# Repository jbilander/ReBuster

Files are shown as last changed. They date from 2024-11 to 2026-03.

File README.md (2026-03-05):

# ReBuster
A drop-in replacement PCB for the Amiga Super Buster chip

This is WORK IN PROGRESS. If you generate gerbers and order PCBs from this source you are doing so completely at your own risk!.

***

<a href="images/ReBuster_pic1.jpg">
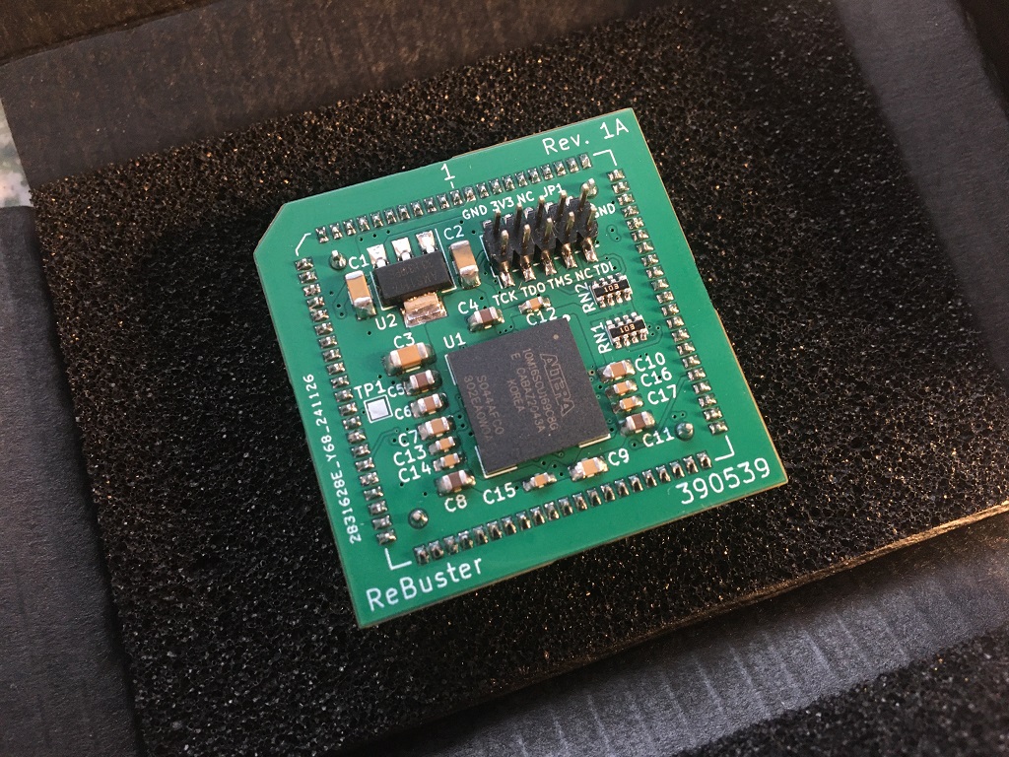
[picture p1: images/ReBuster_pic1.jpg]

</a>
<a href="images/ReBuster_pic2.jpg">
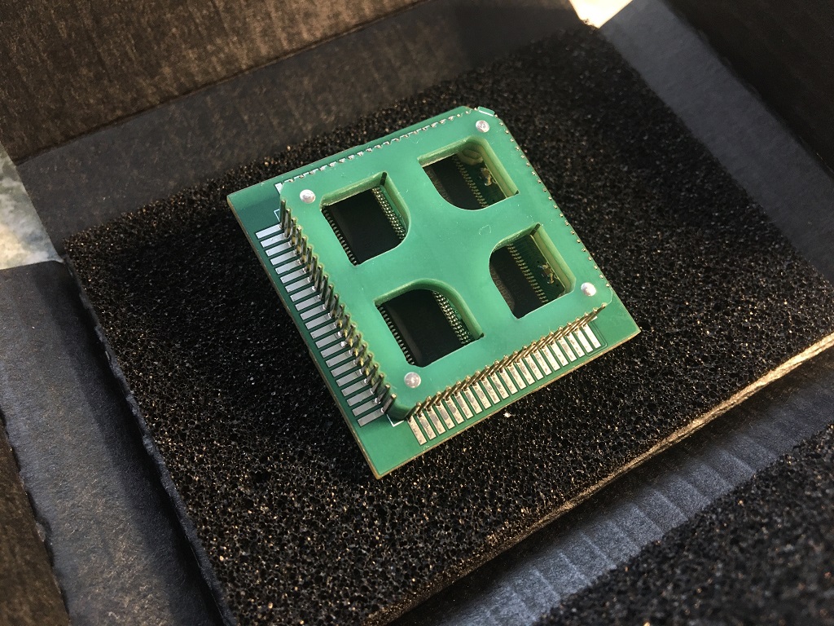
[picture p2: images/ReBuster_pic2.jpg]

</a>
<a href="images/ReBuster_pic3.jpg">
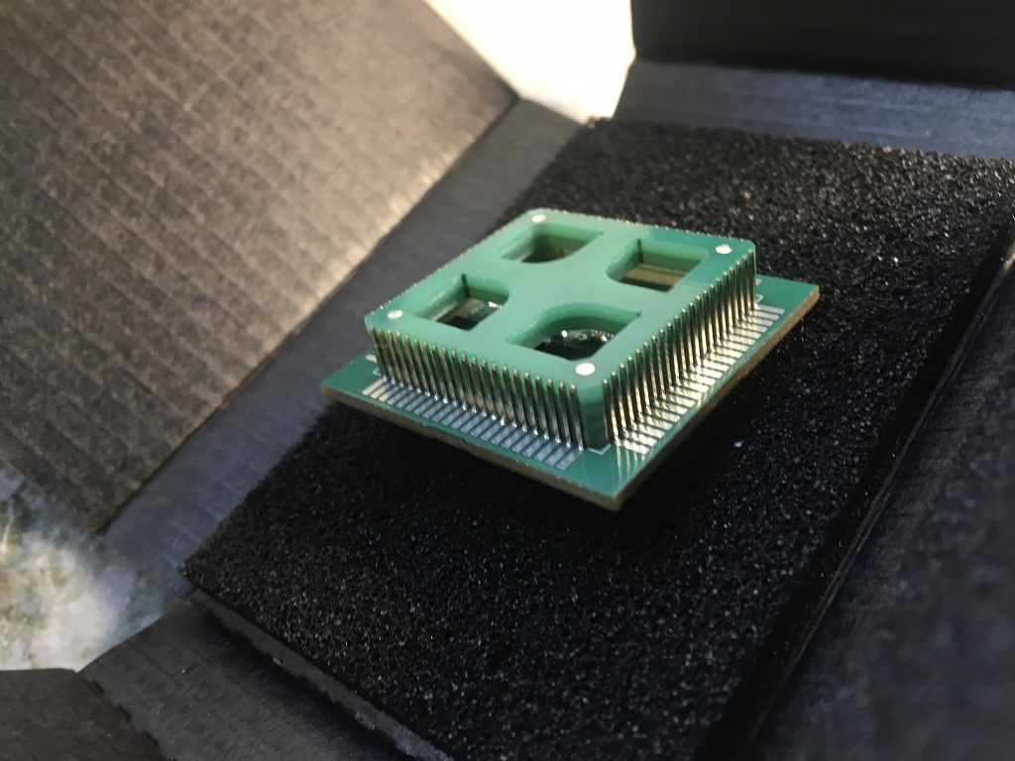
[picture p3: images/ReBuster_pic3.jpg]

</a>

***

<a href="images/ReBuster_screenshot_pic1.png">
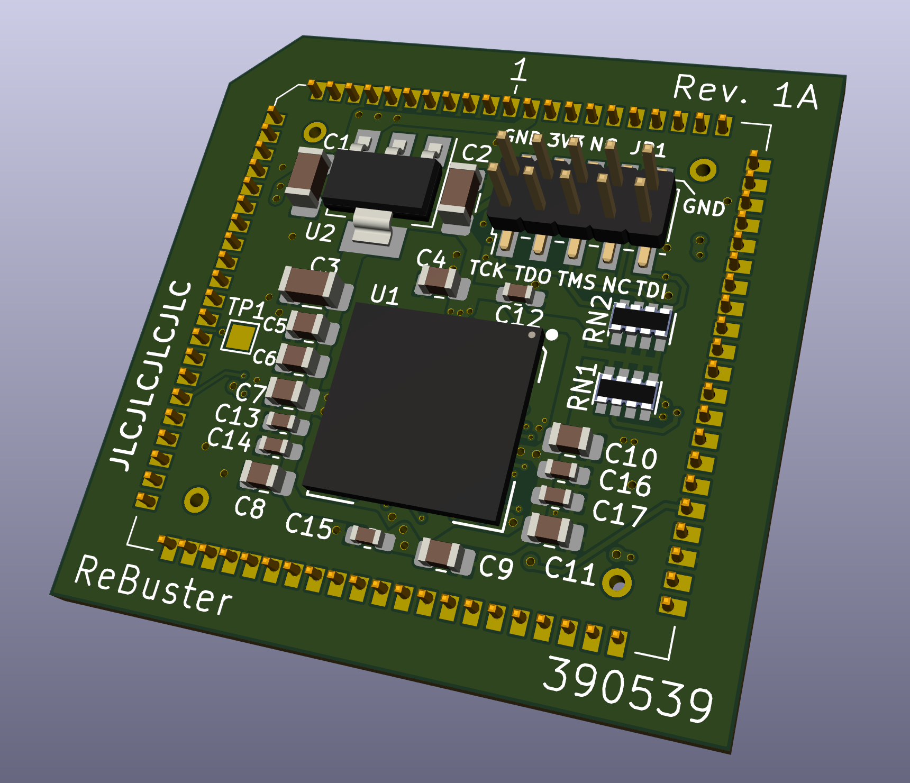
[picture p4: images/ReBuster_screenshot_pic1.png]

</a>
<br />
<a href="images/ReBuster_screenshot_pic2.png">
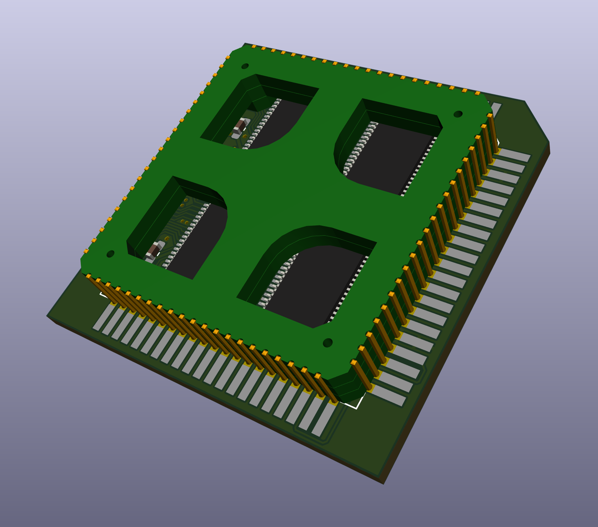
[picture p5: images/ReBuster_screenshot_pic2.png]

</a>
<br />
<a href="images/ReBuster_screenshot_pic3.png">
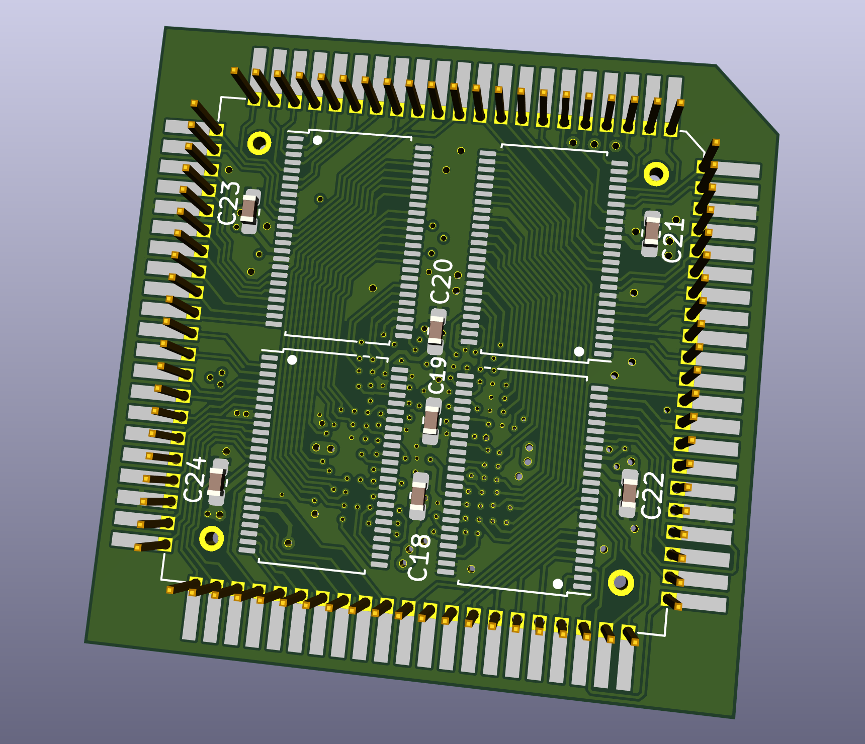
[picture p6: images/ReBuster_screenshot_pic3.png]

</a>

***

<a href="images/pin_assignment_rebuster_rev2a.jpg">
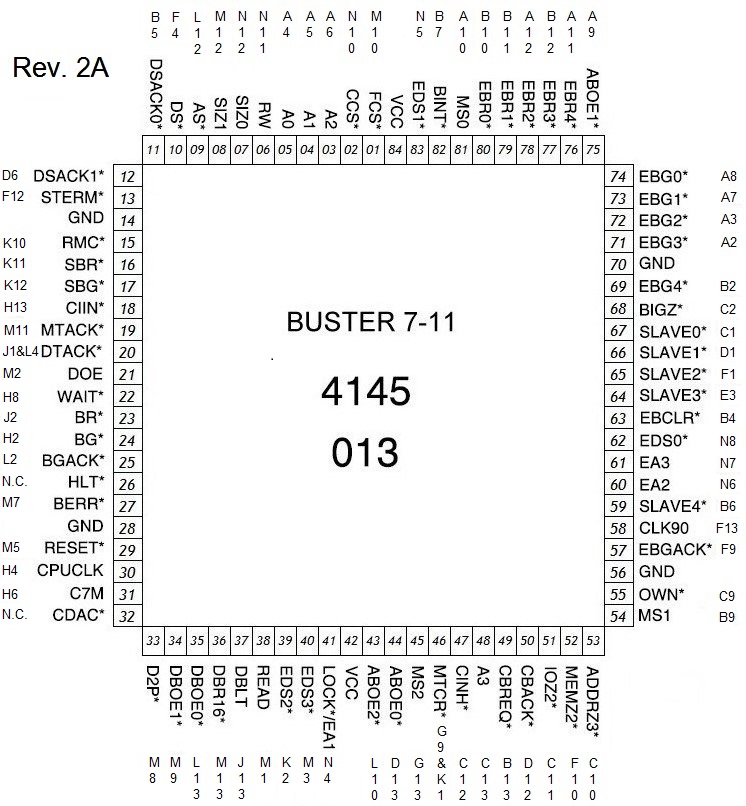
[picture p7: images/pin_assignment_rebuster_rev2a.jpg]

</a>

***

BOM Rev. 2A
---------
Reference  | Name/Value   | Package | Notes
-|-|-|-|
U1 | 10M04SCU169C8G  | BGA-169 11.0x11.0mm_Layout13x13 | Max 10 FPGA [10M04SCU169C8G](https://www.mouser.com/ProductDetail/989-10M04SCU169C8G)
U2 | LM1117-3.3 | SOT-223 | Low-Dropout Linear Regulator 3.3 Volt
U3,U5,U6 | SN74CBTD16210 | TSSOP-48 6.1x12.5mm_P0.5mm | 20-BIT FET Bus switch with level shifting, high-speed TTL-compatible. [74CBTD16210DGGR](https://www.mouser.com/ProductDetail/595-74CBTD16210DGGR)
U4 | SN74LVC16245ADGVR | TSSOP-48_4.4x9.7mm_P0.4mm | 16-bit (dual-octal) noninverting bus transceiver [SN74LVC16245ADGVR](https://www.mouser.com/ProductDetail/595-SNLVC16245ADGVR)
U7 | 74LVC2G07GV | TSOP-6_1.65x3.05mm_P0.95mm | Open Drain noninverting line driver [74LVC2G07GV](https://www.mouser.com/ProductDetail/771-LVC2G07GV125)
U8 | Winslow PLCC-84 Plug | PLCC-84 Plug | Optionally use a home made plug (stacked PCBs)
U9 | PLCC-84_TH_pin_holes | TH_plug_pins | Pins that could be used with the DIY-plug PCBs rev1d for manual fitting, L8.7mm [Aliexpress](https://www.aliexpress.com/item/32893608810.html).
RN1, RN2 | CAY16-1002F4LF RES ARRAY 4 Resistors 10k Ω | 1206 | [CAY16-1002F4LF](https://www.mouser.com/ProductDetail/652-CAY16-1002F4LF)
C1-3 | Capacitor 10uF | 1206 | 
C4,C5,C8,C11 | Capacitor 1uF | 0805 | 
C6,C7,C9,C10 | Capacitor 0.1uF = 100nF | 0805 | 
C12-C19, C21-C23 | Capacitor 0.01uF = 10nF | 0603 |
C20, C24-C28 | Capacitor 0.1uF = 100nF | 0603 |
JTAG | SMT Pin Header Male | SMT 2 x 5 Pin 2.0mm pitch |

***

***

<a href="images/pin_assignment_rebuster_rev1a.jpg">
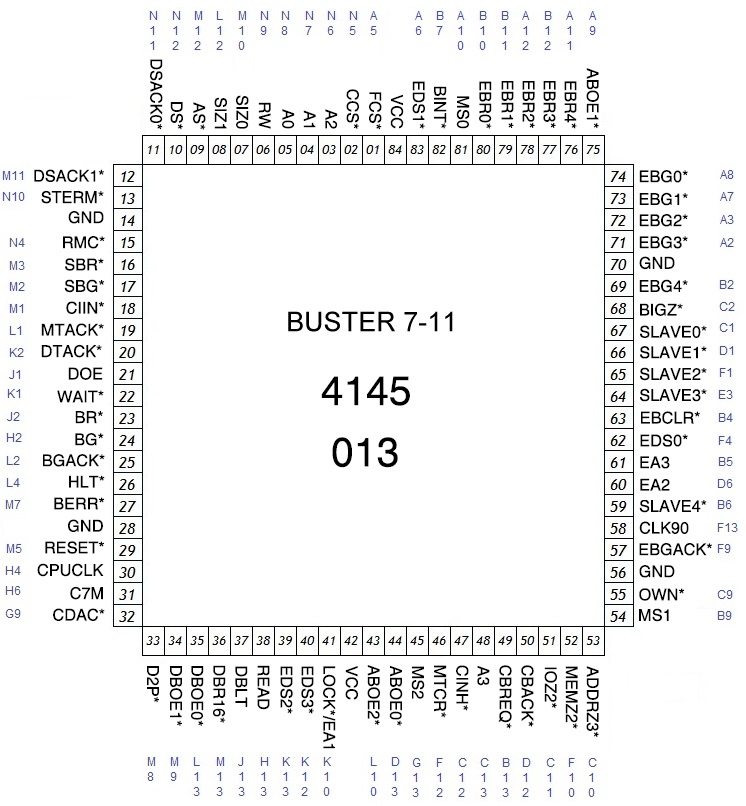
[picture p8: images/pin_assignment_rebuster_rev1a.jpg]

</a>

***

BOM Rev. 1A
---------
Reference  | Name/Value   | Package | Notes
-|-|-|-|
U1 | GW1N-UV9UG169C6/I5  | BGA-169 11.0x11.0mm_Layout13x13 | Gowin FPGA [GW1N-UV9UG169](https://www.mouser.com/ProductDetail/192-GW1NUV9UG169C6I5)
U2 | LM1117-3.3 | SOT-223 | Low-Dropout Linear Regulator 3.3 Volt
U3-U6 | SN74CBTD16210 | TSSOP-48 6.1x12.5mm_P0.5mm | 20-BIT FET Bus switch with level shifting, high-speed TTL-compatible. [74CBTD16210DGGR](https://www.mouser.com/ProductDetail/595-74CBTD16210DGGR)
U7 | Winslow PLCC-84 Plug | PLCC-84 Plug | Optionally use a home made plug (stacked PCBs)
U8 | PLCC-84_TH_pin_holes | TH_plug_pins | Pins that could be used with the DIY-plug PCBs rev1d for manual fitting, L8.7mm [Aliexpress](https://www.aliexpress.com/item/32893608810.html).
RN1, RN2 | CAY16A-4701F4LF RES ARRAY 4 Resistors 4.7k Ω | 1206 | [CAY16A-4701F4LF](https://wwww.mouser.com/ProductDetail/652-CAY16A-4701F4LF)
C1-3 | Capacitor 10uF | 1206 | 
C4,C5,C8,C11 | Capacitor 1uF | 0805 | 
C6,C7,C9,C10 | Capacitor 0.1uF = 100nF | 0805 | 
C12-C19 | Capacitor 0.01uF = 10nF | 0603 |
C20 | Capacitor 0.1uF = 100nF | 0603 |
C21-C24 | Capacitor 0.01uF = 10nF | 0603 |
JTAG | SMT Pin Header Male | SMT 2 x 5 Pin 2.0mm pitch |

***

When ordering from JLCPCB select:

Specify Layer Sequence: Yes

    L1(Top layer):    F_Cu.gbr
    L2(Inner layer1): GND_Cu.gbr
    L3(Inner layer2): VCC_Cu.gbr
    L4(Bottom layer): B_Cu.gbr

Remove Order Number: 

    Specify a location

This will notify JLC where to put the order number, they will replace the "JLCJLCJLCJLC" silkscreen label.

***

[][cc-by-sa]

This work is licensed under a
[Creative Commons Attribution-ShareAlike 4.0 International License][cc-by-sa].

[][cc-by-sa]

[cc-by-sa]: http://creativecommons.org/licenses/by-sa/4.0/
[cc-by-sa-image]: https://licensebuttons.net/l/by-sa/4.0/88x31.png
[cc-by-sa-shield]: https://img.shields.io/badge/License-CC%20BY--SA%204.0-lightgrey.svg

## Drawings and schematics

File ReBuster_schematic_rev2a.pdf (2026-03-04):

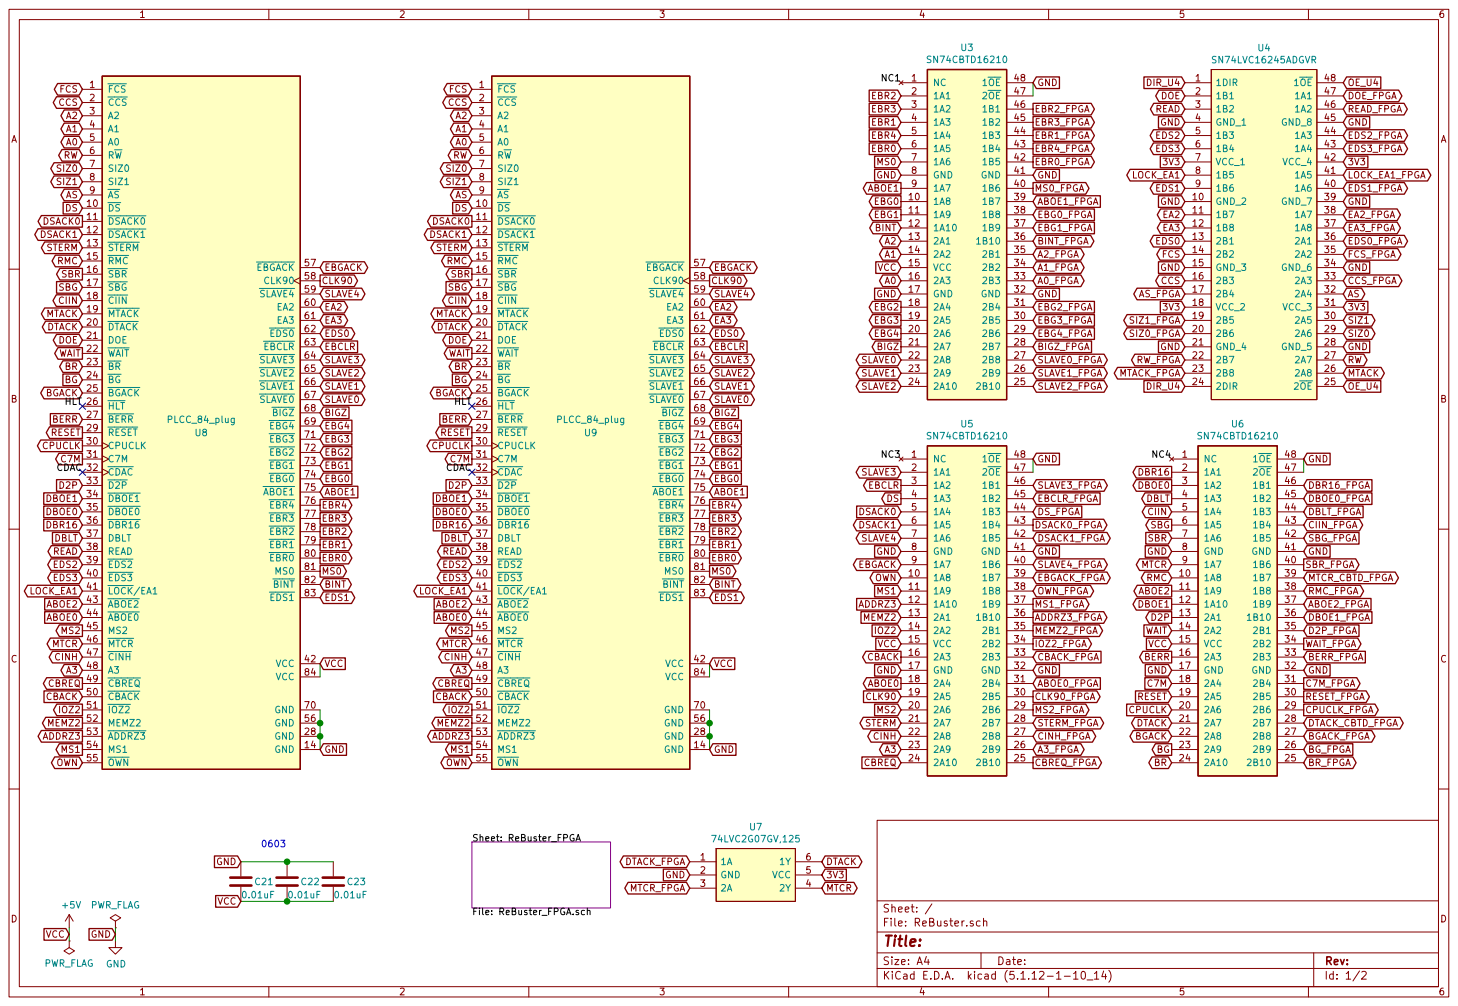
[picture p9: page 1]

SBG
SLAVE4 EA2 EA3 DTACK
CIIN MTACK WAIT BR
ABOE2 CPUCLK DOE
BGACK READ
ABOE0 BERR MTCR
DBLT RESET C7M

Id: 1/2 Title: File: ReBuster.sch Sheet: / Sheet: ReBuster_FPGA

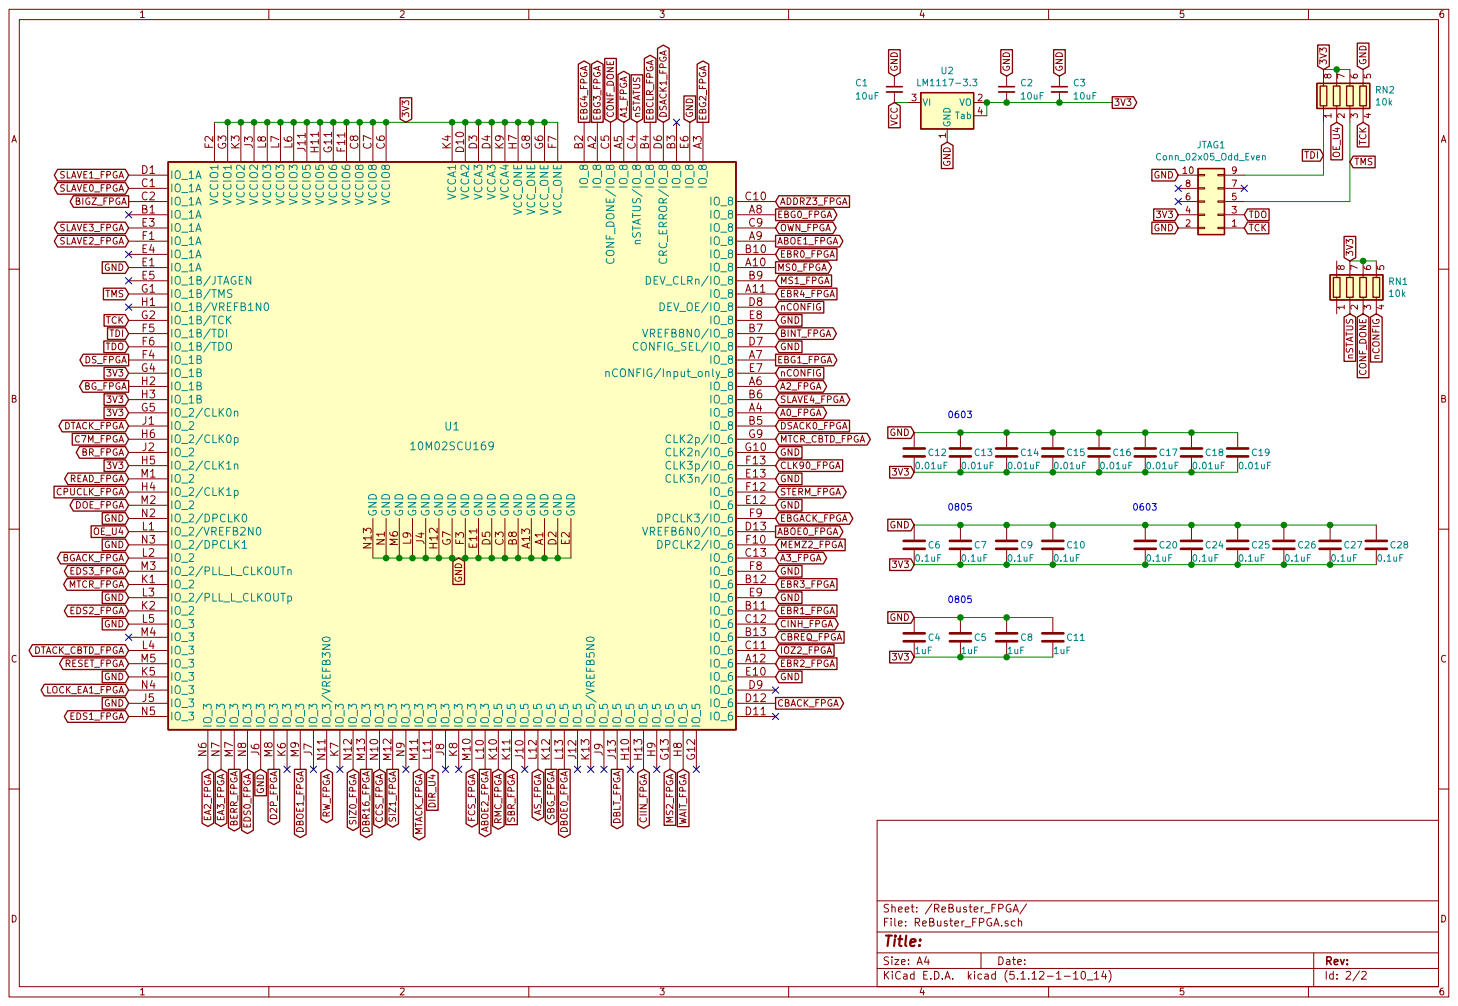
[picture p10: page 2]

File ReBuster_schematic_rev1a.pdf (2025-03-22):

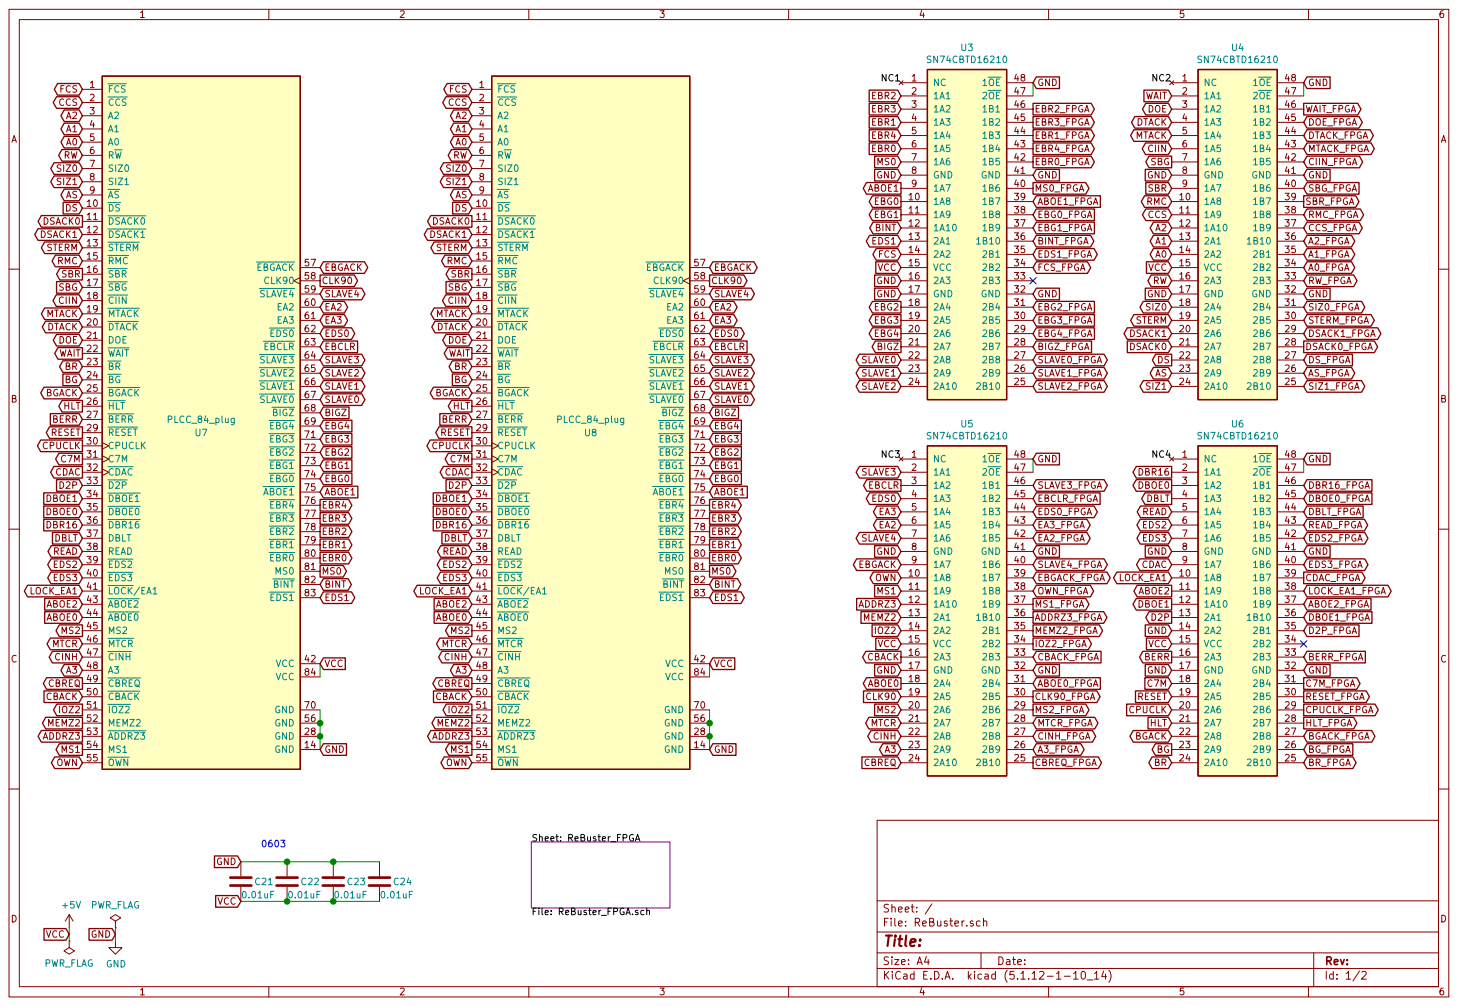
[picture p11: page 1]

SBG
CIIN MTACK WAIT BR

Id: 1/2 Title: File: ReBuster.sch Sheet: / Sheet: ReBuster_FPGA

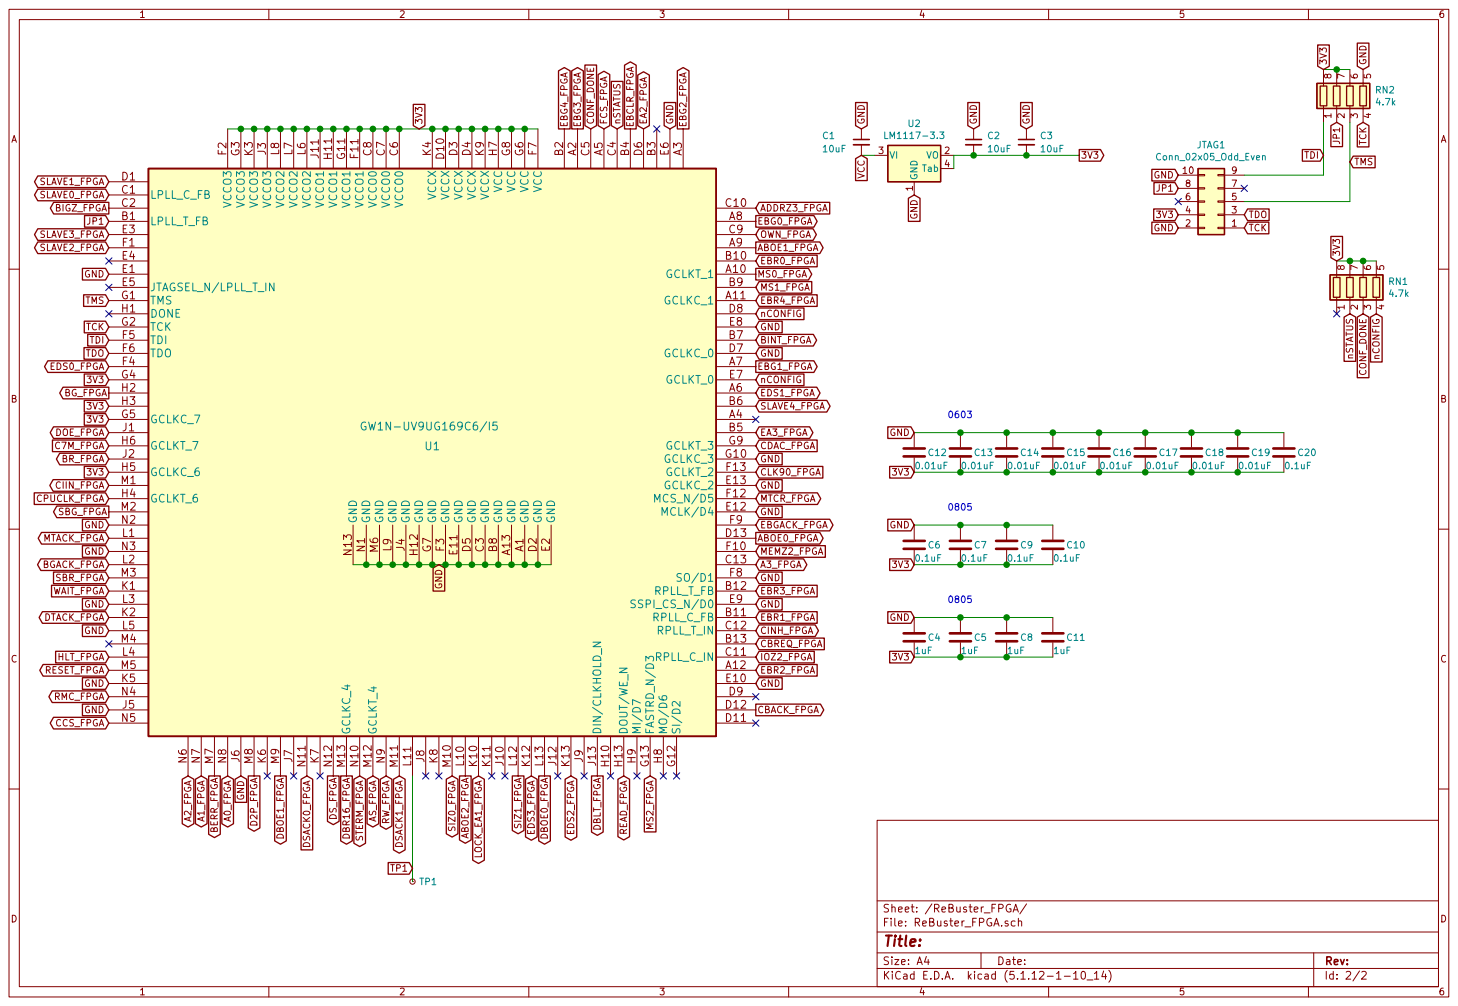
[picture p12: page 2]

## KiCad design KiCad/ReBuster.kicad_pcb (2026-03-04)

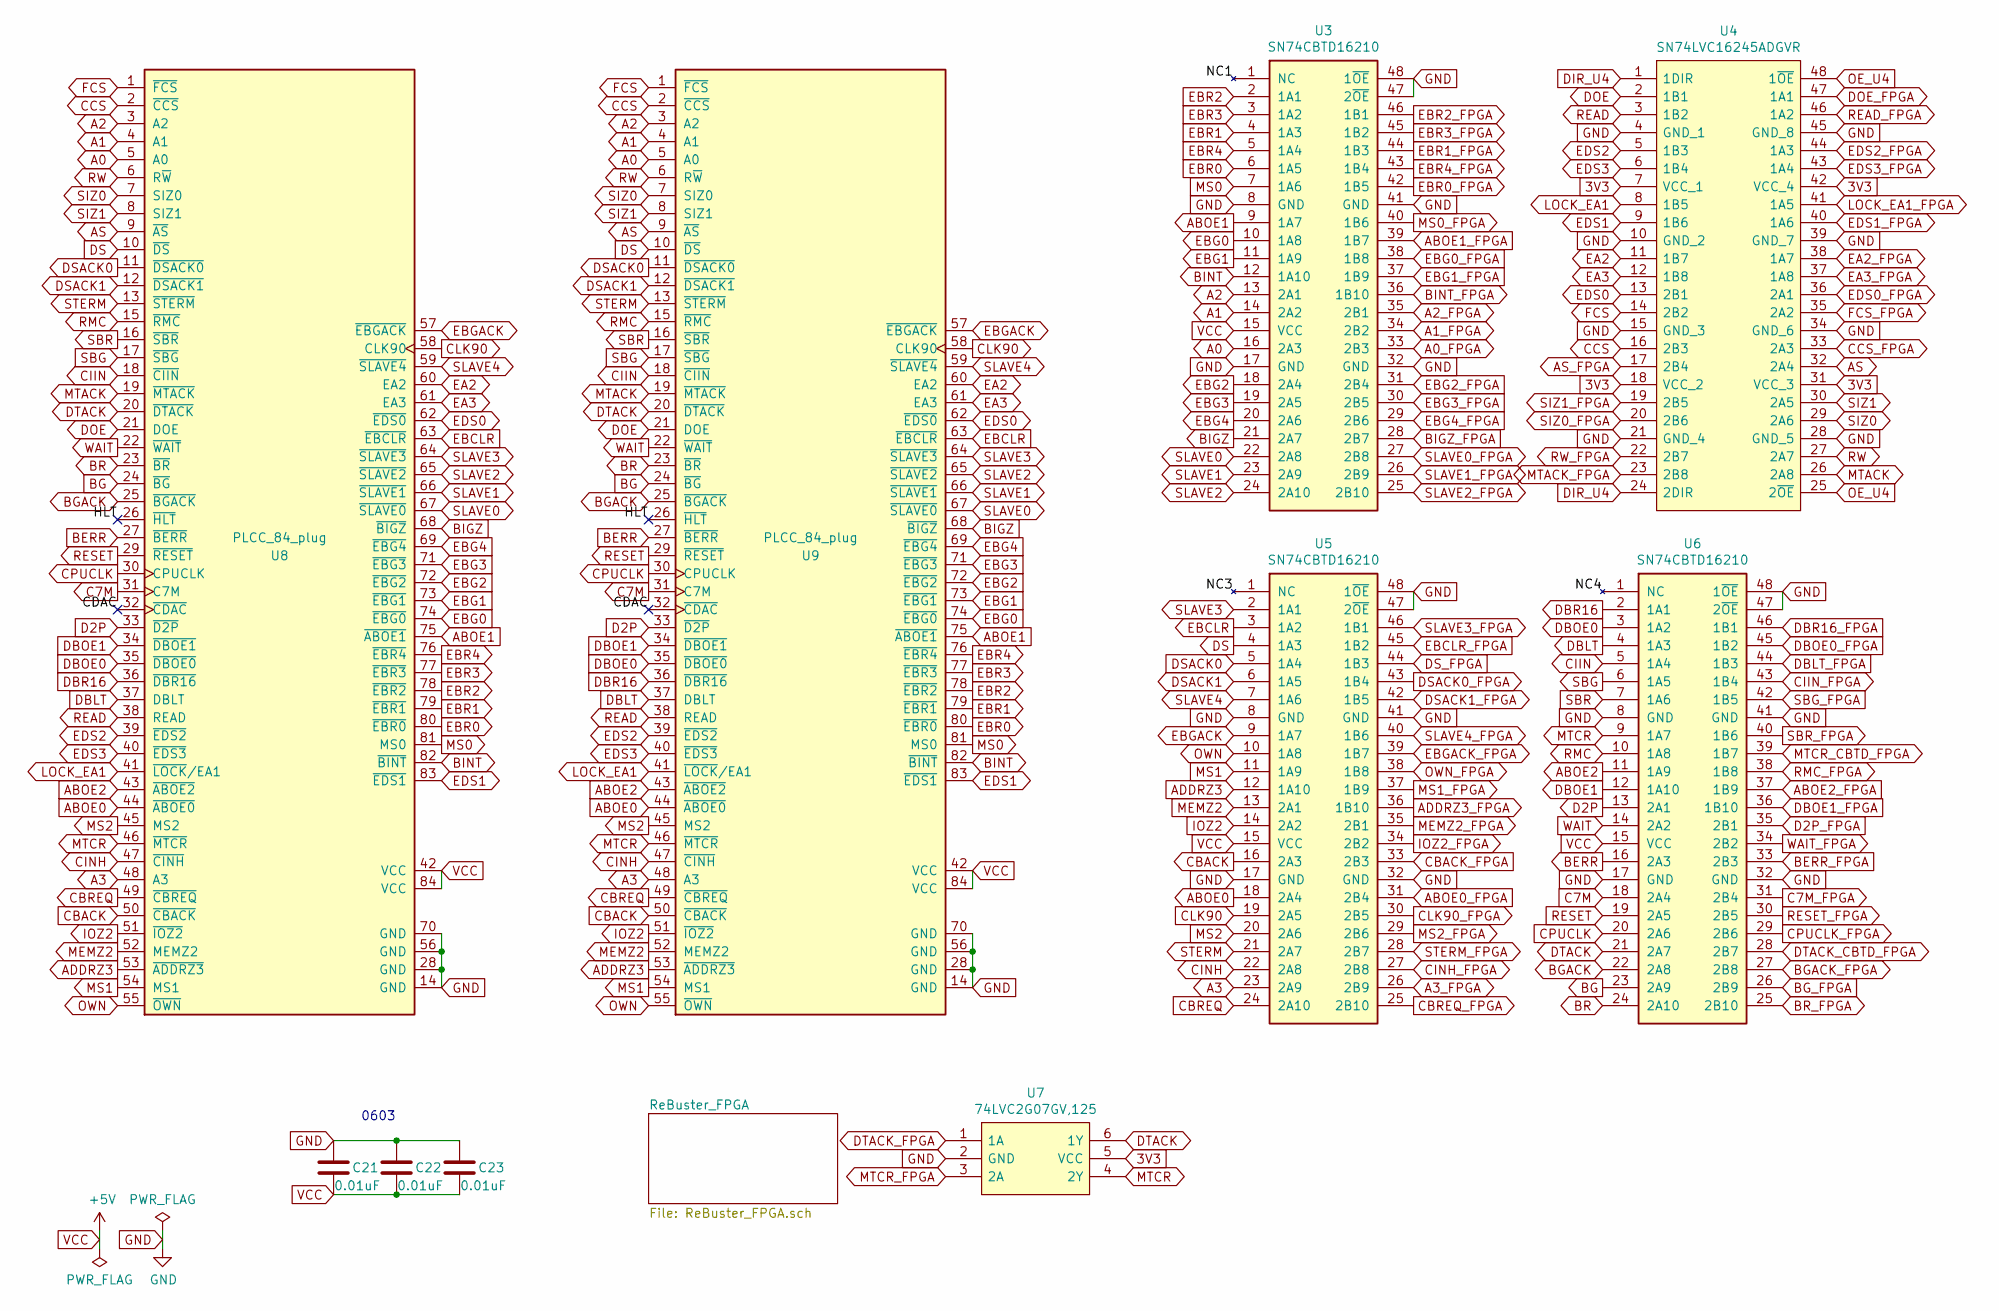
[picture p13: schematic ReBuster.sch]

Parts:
C21, C22, C23: 0.01uF; C_0603_1608Metric_Pad1.05x0.95mm_HandSolder
U3, U5, U6: SN74CBTD16210; TSSOP-48_6.1x12.5mm_P0.5mm_padLength_1mm
U4: SN74LVC16245ADGVR; TSSOP-48_4.4x9.7mm_P0.4mm_custom
U7: 74LVC2G07GV,125; TSOP-6_1.65x3.05mm_P0.95mm
U8: PLCC_84_plug; PLCC-84_Plug_P1.27mm_mirrored
U9: PLCC_84_plug; PLCC-84_TH_pin_holes

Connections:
3V3: U4.7 (VCC_1), U4.18 (VCC_2), U4.31 (VCC_3), U4.42 (VCC_4), U7.5 (VCC); also elsewhere on the board
/CDAC: U8.32 (~CDAC), U9.32 (~CDAC)
/HLT: U8.26 (~HLT), U9.26 (~HLT)
/NC1: U3.1 (NC)
/NC3: U5.1 (NC)
/NC4: U6.1 (NC)
A0: U3.16 (2A3), U8.5 (A0), U9.5 (A0)
A0_FPGA: U3.33 (2B3); also elsewhere on the board
A1: U3.14 (2A2), U8.4 (A1), U9.4 (A1)
A1_FPGA: U3.34 (2B2); also elsewhere on the board
A2: U3.13 (2A1), U8.3 (A2), U9.3 (A2)
A2_FPGA: U3.35 (2B1); also elsewhere on the board
A3: U5.23 (2A9), U8.48 (A3), U9.48 (A3)
A3_FPGA: U5.26 (2B9); also elsewhere on the board
ABOE0: U5.18 (2A4), U8.44 (~ABOE0), U9.44 (~ABOE0)
ABOE0_FPGA: U5.31 (2B4); also elsewhere on the board
ABOE1: U3.9 (1A7), U8.75 (~ABOE1), U9.75 (~ABOE1)
ABOE1_FPGA: U3.39 (1B7); also elsewhere on the board
ABOE2: U6.11 (1A9), U8.43 (~ABOE2), U9.43 (~ABOE2)
ABOE2_FPGA: U6.37 (1B9); also elsewhere on the board
ADDRZ3: U5.12 (1A10), U8.53 (~ADDRZ3), U9.53 (~ADDRZ3)
ADDRZ3_FPGA: U5.36 (1B10); also elsewhere on the board
AS: U4.32 (2A4), U8.9 (~AS), U9.9 (~AS)
AS_FPGA: U4.17 (2B4); also elsewhere on the board
BERR: U6.16 (2A3), U8.27 (~BERR), U9.27 (~BERR)
BERR_FPGA: U6.33 (2B3); also elsewhere on the board
BG: U6.23 (2A9), U8.24 (~BG), U9.24 (~BG)
BGACK: U6.22 (2A8), U8.25 (~BGACK), U9.25 (~BGACK)
BGACK_FPGA: U6.27 (2B8); also elsewhere on the board
BG_FPGA: U6.26 (2B9); also elsewhere on the board
BIGZ: U3.21 (2A7), U8.68 (~BIGZ), U9.68 (~BIGZ)
BIGZ_FPGA: U3.28 (2B7); also elsewhere on the board
BINT: U3.12 (1A10), U8.82 (~BINT), U9.82 (~BINT)
BINT_FPGA: U3.36 (1B10); also elsewhere on the board
BR: U6.24 (2A10), U8.23 (~BR), U9.23 (~BR)
BR_FPGA: U6.25 (2B10); also elsewhere on the board
C7M: U6.18 (2A4), U8.31 (C7M), U9.31 (C7M)
C7M_FPGA: U6.31 (2B4); also elsewhere on the board
CBACK: U5.16 (2A3), U8.50 (~CBACK), U9.50 (~CBACK)
CBACK_FPGA: U5.33 (2B3); also elsewhere on the board
CBREQ: U5.24 (2A10), U8.49 (~CBREQ), U9.49 (~CBREQ)
CBREQ_FPGA: U5.25 (2B10); also elsewhere on the board
CCS: U4.16 (2B3), U8.2 (~CCS), U9.2 (~CCS)
CCS_FPGA: U4.33 (2A3); also elsewhere on the board
CIIN: U6.5 (1A4), U8.18 (~CIIN), U9.18 (~CIIN)
CIIN_FPGA: U6.43 (1B4); also elsewhere on the board
CINH: U5.22 (2A8), U8.47 (~CINH), U9.47 (~CINH)
CINH_FPGA: U5.27 (2B8); also elsewhere on the board
CLK90: U5.19 (2A5), U8.58 (CLK90), U9.58 (CLK90)
CLK90_FPGA: U5.30 (2B5); also elsewhere on the board
CPUCLK: U6.20 (2A6), U8.30 (CPUCLK), U9.30 (CPUCLK)
CPUCLK_FPGA: U6.29 (2B6); also elsewhere on the board
D2P: U6.13 (2A1), U8.33 (~D2P), U9.33 (~D2P)
D2P_FPGA: U6.35 (2B1); also elsewhere on the board
DBLT: U6.4 (1A3), U8.37 (DBLT), U9.37 (DBLT)
DBLT_FPGA: U6.44 (1B3); also elsewhere on the board
DBOE0: U6.3 (1A2), U8.35 (~DBOE0), U9.35 (~DBOE0)
DBOE0_FPGA: U6.45 (1B2); also elsewhere on the board
DBOE1: U6.12 (1A10), U8.34 (~DBOE1), U9.34 (~DBOE1)
DBOE1_FPGA: U6.36 (1B10); also elsewhere on the board
DBR16: U6.2 (1A1), U8.36 (~DBR16), U9.36 (~DBR16)
DBR16_FPGA: U6.46 (1B1); also elsewhere on the board
DIR_U4: U4.1 (1DIR), U4.24 (2DIR); also elsewhere on the board
DOE: U4.2 (1B1), U8.21 (DOE), U9.21 (DOE)
DOE_FPGA: U4.47 (1A1); also elsewhere on the board
DS: U5.4 (1A3), U8.10 (~DS), U9.10 (~DS)
DSACK0: U5.5 (1A4), U8.11 (~DSACK0), U9.11 (~DSACK0)
DSACK0_FPGA: U5.43 (1B4); also elsewhere on the board
DSACK1: U5.6 (1A5), U8.12 (~DSACK1), U9.12 (~DSACK1)
DSACK1_FPGA: U5.42 (1B5); also elsewhere on the board
DS_FPGA: U5.44 (1B3); also elsewhere on the board
DTACK: U6.21 (2A7), U7.6 (1Y), U8.20 (~DTACK), U9.20 (~DTACK)
DTACK_CBTD_FPGA: U6.28 (2B7); also elsewhere on the board
DTACK_FPGA: U7.1 (1A); also elsewhere on the board
EA2: U4.11 (1B7), U8.60 (EA2), U9.60 (EA2)
EA2_FPGA: U4.38 (1A7); also elsewhere on the board
EA3: U4.12 (1B8), U8.61 (EA3), U9.61 (EA3)
EA3_FPGA: U4.37 (1A8); also elsewhere on the board
EBCLR: U5.3 (1A2), U8.63 (~EBCLR), U9.63 (~EBCLR)
EBCLR_FPGA: U5.45 (1B2); also elsewhere on the board
EBG0: U3.10 (1A8), U8.74 (~EBG0), U9.74 (~EBG0)
EBG0_FPGA: U3.38 (1B8); also elsewhere on the board
EBG1: U3.11 (1A9), U8.73 (~EBG1), U9.73 (~EBG1)
EBG1_FPGA: U3.37 (1B9); also elsewhere on the board
EBG2: U3.18 (2A4), U8.72 (~EBG2), U9.72 (~EBG2)
EBG2_FPGA: U3.31 (2B4); also elsewhere on the board
EBG3: U3.19 (2A5), U8.71 (~EBG3), U9.71 (~EBG3)
EBG3_FPGA: U3.30 (2B5); also elsewhere on the board
EBG4: U3.20 (2A6), U8.69 (~EBG4), U9.69 (~EBG4)
EBG4_FPGA: U3.29 (2B6); also elsewhere on the board
EBGACK: U5.9 (1A7), U8.57 (~EBGACK), U9.57 (~EBGACK)
EBGACK_FPGA: U5.39 (1B7); also elsewhere on the board
EBR0: U3.6 (1A5), U8.80 (~EBR0), U9.80 (~EBR0)
EBR0_FPGA: U3.42 (1B5); also elsewhere on the board
EBR1: U3.4 (1A3), U8.79 (~EBR1), U9.79 (~EBR1)
EBR1_FPGA: U3.44 (1B3); also elsewhere on the board
EBR2: U3.2 (1A1), U8.78 (~EBR2), U9.78 (~EBR2)
EBR2_FPGA: U3.46 (1B1); also elsewhere on the board
EBR3: U3.3 (1A2), U8.77 (~EBR3), U9.77 (~EBR3)
EBR3_FPGA: U3.45 (1B2); also elsewhere on the board
EBR4: U3.5 (1A4), U8.76 (~EBR4), U9.76 (~EBR4)
EBR4_FPGA: U3.43 (1B4); also elsewhere on the board
EDS0: U4.13 (2B1), U8.62 (~EDS0), U9.62 (~EDS0)
EDS0_FPGA: U4.36 (2A1); also elsewhere on the board
EDS1: U4.9 (1B6), U8.83 (~EDS1), U9.83 (~EDS1)
EDS1_FPGA: U4.40 (1A6); also elsewhere on the board
EDS2: U4.5 (1B3), U8.39 (~EDS2), U9.39 (~EDS2)
EDS2_FPGA: U4.44 (1A3); also elsewhere on the board
EDS3: U4.6 (1B4), U8.40 (~EDS3), U9.40 (~EDS3)
EDS3_FPGA: U4.43 (1A4); also elsewhere on the board
FCS: U4.14 (2B2), U8.1 (~FCS), U9.1 (~FCS)
FCS_FPGA: U4.35 (2A2); also elsewhere on the board
GND: C21.1, C22.1, C23.1, U3.8 (GND), U3.17 (GND), U3.32 (GND), U3.41 (GND), U3.47 (2~OE), U3.48 (1~OE), U4.4 (GND_1), U4.10 (GND_2), U4.15 (GND_3), U4.21 (GND_4), U4.28 (GND_5), U4.34 (GND_6), U4.39 (GND_7), U4.45 (GND_8), U5.8 (GND), U5.17 (GND), U5.32 (GND), U5.41 (GND), U5.47 (2~OE), U5.48 (1~OE), U6.8 (GND), U6.17 (GND), U6.32 (GND), U6.41 (GND), U6.47 (2~OE), U6.48 (1~OE), U7.2 (GND), U8.14 (GND), U8.28 (GND), U8.56 (GND), U8.70 (GND), U9.14 (GND), U9.28 (GND), U9.56 (GND), U9.70 (GND); also elsewhere on the board
IOZ2: U5.14 (2A2), U8.51 (~IOZ2), U9.51 (~IOZ2)
IOZ2_FPGA: U5.34 (2B2); also elsewhere on the board
LOCK_EA1: U4.8 (1B5), U8.41 (~LOCK~/EA1), U9.41 (~LOCK~/EA1)
LOCK_EA1_FPGA: U4.41 (1A5); also elsewhere on the board
MEMZ2: U5.13 (2A1), U8.52 (MEMZ2), U9.52 (MEMZ2)
MEMZ2_FPGA: U5.35 (2B1); also elsewhere on the board
MS0: U3.7 (1A6), U8.81 (MS0), U9.81 (MS0)
MS0_FPGA: U3.40 (1B6); also elsewhere on the board
MS1: U5.11 (1A9), U8.54 (MS1), U9.54 (MS1)
MS1_FPGA: U5.37 (1B9); also elsewhere on the board
MS2: U5.20 (2A6), U8.45 (MS2), U9.45 (MS2)
MS2_FPGA: U5.29 (2B6); also elsewhere on the board
MTACK: U4.26 (2A8), U8.19 (~MTACK), U9.19 (~MTACK)
MTACK_FPGA: U4.23 (2B8); also elsewhere on the board
MTCR: U6.9 (1A7), U7.4 (2Y), U8.46 (~MTCR), U9.46 (~MTCR)
MTCR_CBTD_FPGA: U6.39 (1B7); also elsewhere on the board
MTCR_FPGA: U7.3 (2A); also elsewhere on the board
OE_U4: U4.25 (2~OE), U4.48 (1~OE); also elsewhere on the board
OWN: U5.10 (1A8), U8.55 (~OWN), U9.55 (~OWN)
OWN_FPGA: U5.38 (1B8); also elsewhere on the board
READ: U4.3 (1B2), U8.38 (READ), U9.38 (READ)
READ_FPGA: U4.46 (1A2); also elsewhere on the board
RESET: U6.19 (2A5), U8.29 (~RESET), U9.29 (~RESET)
RESET_FPGA: U6.30 (2B5); also elsewhere on the board
RMC: U6.10 (1A8), U8.15 (~RMC), U9.15 (~RMC)
RMC_FPGA: U6.38 (1B8); also elsewhere on the board
RW: U4.27 (2A7), U8.6 (R~W), U9.6 (R~W)
RW_FPGA: U4.22 (2B7); also elsewhere on the board
SBG: U6.6 (1A5), U8.17 (~SBG), U9.17 (~SBG)
SBG_FPGA: U6.42 (1B5); also elsewhere on the board
SBR: U6.7 (1A6), U8.16 (~SBR), U9.16 (~SBR)
SBR_FPGA: U6.40 (1B6); also elsewhere on the board
SIZ0: U4.29 (2A6), U8.7 (SIZ0), U9.7 (SIZ0)
SIZ0_FPGA: U4.20 (2B6); also elsewhere on the board
SIZ1: U4.30 (2A5), U8.8 (SIZ1), U9.8 (SIZ1)
SIZ1_FPGA: U4.19 (2B5); also elsewhere on the board
SLAVE0: U3.22 (2A8), U8.67 (~SLAVE0), U9.67 (~SLAVE0)
SLAVE0_FPGA: U3.27 (2B8); also elsewhere on the board
SLAVE1: U3.23 (2A9), U8.66 (~SLAVE1), U9.66 (~SLAVE1)
SLAVE1_FPGA: U3.26 (2B9); also elsewhere on the board
SLAVE2: U3.24 (2A10), U8.65 (~SLAVE2), U9.65 (~SLAVE2)
SLAVE2_FPGA: U3.25 (2B10); also elsewhere on the board
SLAVE3: U5.2 (1A1), U8.64 (~SLAVE3), U9.64 (~SLAVE3)
SLAVE3_FPGA: U5.46 (1B1); also elsewhere on the board
SLAVE4: U5.7 (1A6), U8.59 (~SLAVE4), U9.59 (~SLAVE4)
SLAVE4_FPGA: U5.40 (1B6); also elsewhere on the board
STERM: U5.21 (2A7), U8.13 (~STERM), U9.13 (~STERM)
STERM_FPGA: U5.28 (2B7); also elsewhere on the board
VCC: C21.2, C22.2, C23.2, U3.15 (VCC), U5.15 (VCC), U6.15 (VCC), U8.42 (VCC), U8.84 (VCC), U9.42 (VCC), U9.84 (VCC); also elsewhere on the board
WAIT: U6.14 (2A2), U8.22 (~WAIT), U9.22 (~WAIT)
WAIT_FPGA: U6.34 (2B2); also elsewhere on the board

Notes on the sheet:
0603

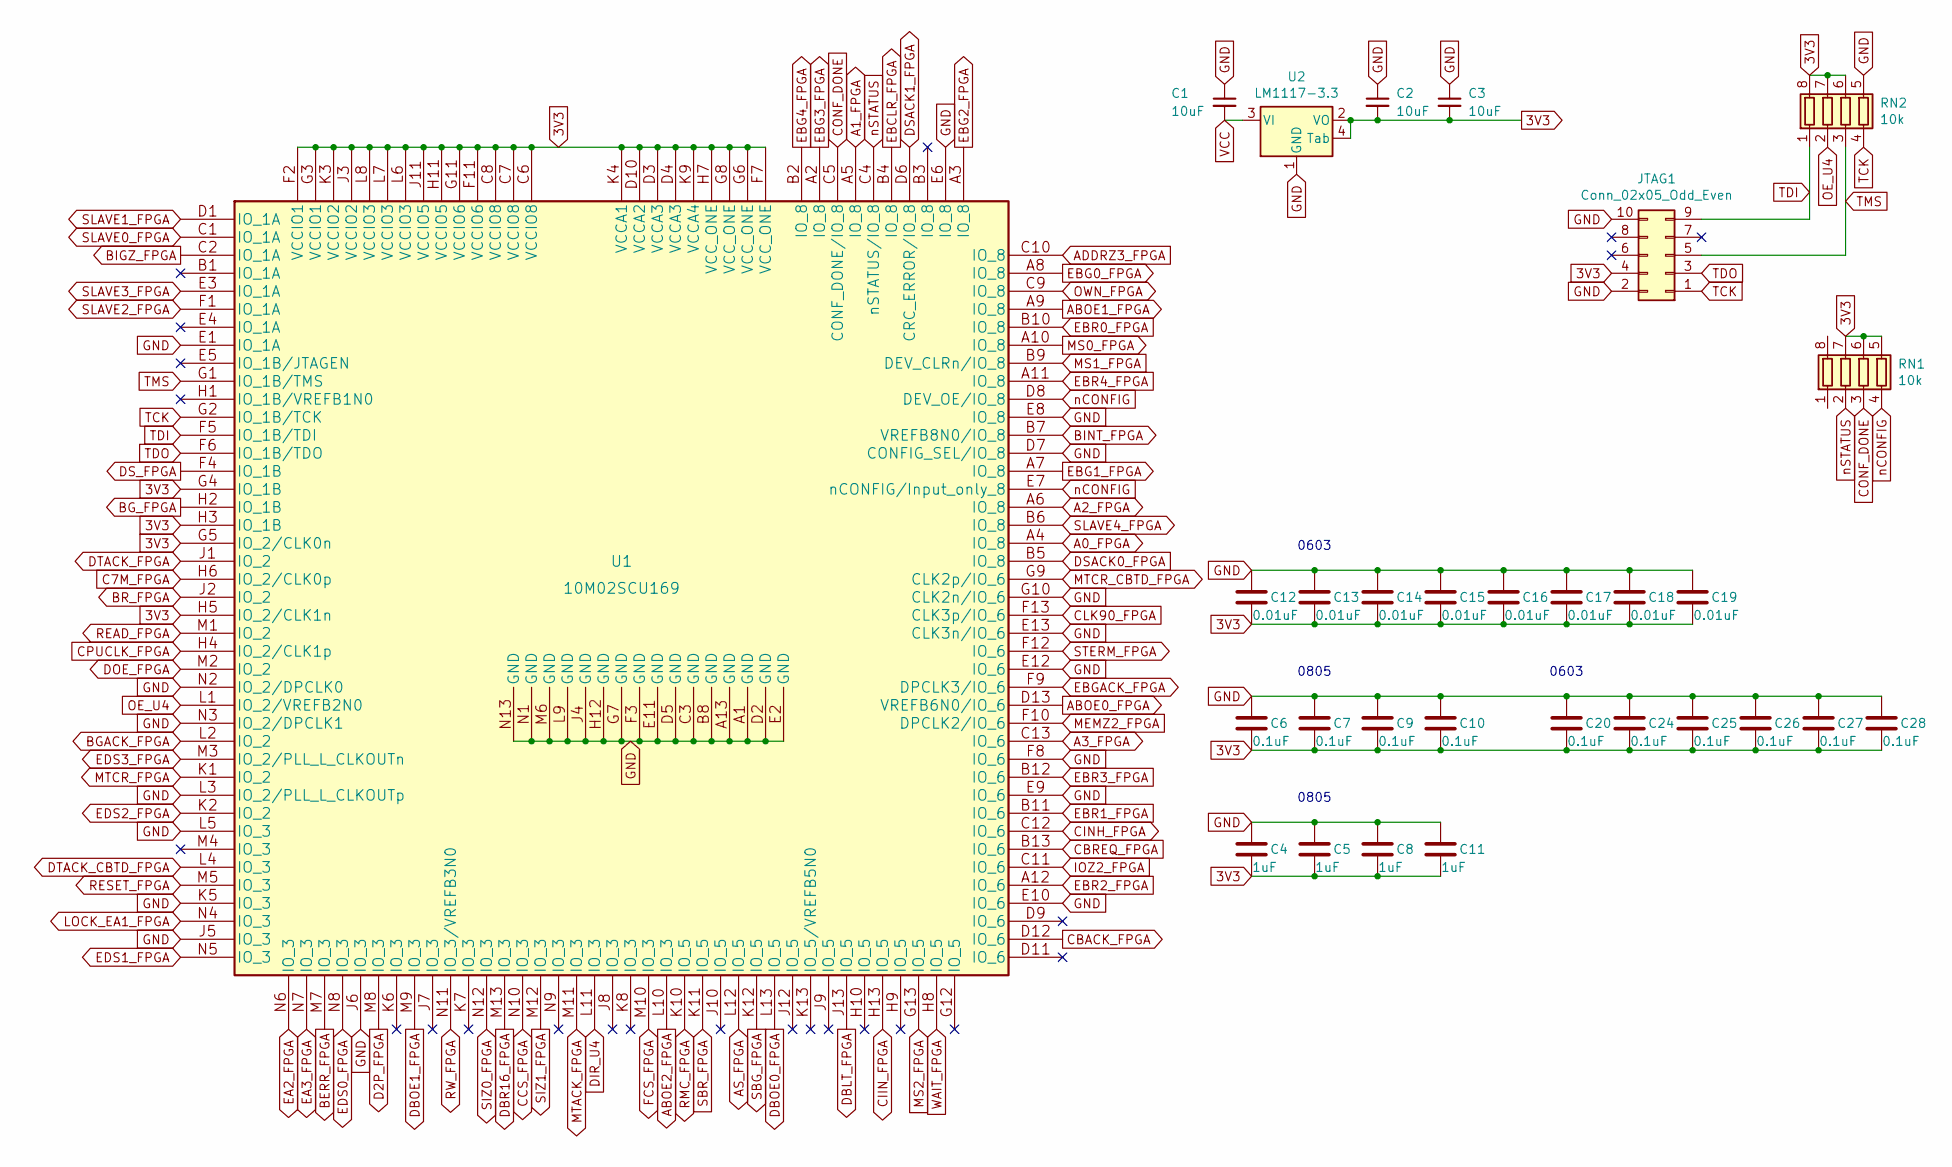
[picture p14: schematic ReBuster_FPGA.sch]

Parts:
C1, C2, C3: 10uF; C_1206_3216Metric_Pad1.42x1.75mm_HandSolder
C4, C5, C8, C11: 1uF; C_0805_2012Metric_Pad1.15x1.40mm_HandSolder
C6, C7, C9, C10: 0.1uF; C_0805_2012Metric_Pad1.15x1.40mm_HandSolder
C12, C13, C14, C15, C16, C17, C19: 0.01uF; C_0603_1608Metric_Pad1.05x0.95mm_HandSolder
C18: 0.01uF; C_0603_1608Metric
C20: 0.1uF; C_0603_1608Metric_Pad1.05x0.95mm_HandSolder
C24, C25, C28: 0.1uF; C_0603_1608Metric_Pad1.05x0.95mm_HandSolder_extended
C26, C27: 0.1uF; C_0603_1608Metric_Pad1.08x0.95mm_HandSolder
JTAG1: Conn_02x05_Odd_Even; PinHeader_2x05_P2.00mm_Vertical_SMD
RN1, RN2: 10k; RESCAF80P320X160X60-8N
U1: 10M02SCU169; BGA-169_11.0x11.0mm_Layout13x13_P0.8mm_Ball0.5mm_Pad0.35mm_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
U2: LM1117-3.3; SOT-223

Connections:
3V3: C2.2, C3.2, C4.2, C5.2, C6.2, C7.2, C8.2, C9.2, C10.2, C11.2, C12.2, C13.2, C14.2, C15.2, C16.2, C17.2, C18.2, C19.2, C20.2, C24.2, C25.2, C26.2, C27.2, C28.2, JTAG1.4, RN1.5 (R4.2), RN1.6 (R3.2), RN1.7 (R2.2), RN2.6 (R3.2), RN2.7 (R2.2), RN2.8 (R1.2), U1.C6 (VCCIO8), U1.C7 (VCCIO8), U1.C8 (VCCIO8), U1.D3 (VCCA3), U1.D4 (VCCA3), U1.D10 (VCCA2), U1.F2 (VCCIO1), U1.F7 (VCC_ONE), U1.F11 (VCCIO6), U1.G3 (VCCIO1), U1.G4 (IO_1B), U1.G5 (IO_2/CLK0n), U1.G6 (VCC_ONE), U1.G8 (VCC_ONE), U1.G11 (VCCIO6), U1.H3 (IO_1B), U1.H5 (IO_2/CLK1n), U1.H7 (VCC_ONE), U1.H11 (VCCIO5), U1.J3 (VCCIO2), U1.J11 (VCCIO5), U1.K3 (VCCIO2), U1.K4 (VCCA1), U1.K9 (VCCA4), U1.L6 (VCCIO3), U1.L7 (VCCIO3), U1.L8 (VCCIO3), U2.2 (VO), U2.4 (Tab); also elsewhere on the board
A0_FPGA: U1.A4 (IO_8); also elsewhere on the board
A1_FPGA: U1.A5 (IO_8); also elsewhere on the board
A2_FPGA: U1.A6 (IO_8); also elsewhere on the board
A3_FPGA: U1.C13 (IO_6); also elsewhere on the board
ABOE0_FPGA: U1.D13 (VREFB6N0/IO_6); also elsewhere on the board
ABOE1_FPGA: U1.A9 (IO_8); also elsewhere on the board
ABOE2_FPGA: U1.L10 (IO_3); also elsewhere on the board
ADDRZ3_FPGA: U1.C10 (IO_8); also elsewhere on the board
AS_FPGA: U1.L12 (IO_5); also elsewhere on the board
BERR_FPGA: U1.M7 (IO_3); also elsewhere on the board
BGACK_FPGA: U1.L2 (IO_2); also elsewhere on the board
BG_FPGA: U1.H2 (IO_1B); also elsewhere on the board
BIGZ_FPGA: U1.C2 (IO_1A); also elsewhere on the board
BINT_FPGA: U1.B7 (VREFB8N0/IO_8); also elsewhere on the board
BR_FPGA: U1.J2 (IO_2); also elsewhere on the board
C7M_FPGA: U1.H6 (IO_2/CLK0p); also elsewhere on the board
CBACK_FPGA: U1.D12 (IO_6); also elsewhere on the board
CBREQ_FPGA: U1.B13 (IO_6); also elsewhere on the board
CCS_FPGA: U1.N10 (IO_3); also elsewhere on the board
CIIN_FPGA: U1.H13 (IO_5); also elsewhere on the board
CINH_FPGA: U1.C12 (IO_6); also elsewhere on the board
CLK90_FPGA: U1.F13 (CLK3p/IO_6); also elsewhere on the board
CONF_DONE: RN1.3 (R3.1), U1.C5 (CONF_DONE/IO_8)
CPUCLK_FPGA: U1.H4 (IO_2/CLK1p); also elsewhere on the board
D2P_FPGA: U1.M8 (IO_3); also elsewhere on the board
DBLT_FPGA: U1.J13 (IO_5); also elsewhere on the board
DBOE0_FPGA: U1.L13 (IO_5); also elsewhere on the board
DBOE1_FPGA: U1.M9 (IO_3); also elsewhere on the board
DBR16_FPGA: U1.M13 (IO_3); also elsewhere on the board
DIR_U4: U1.L11 (IO_3); also elsewhere on the board
DOE_FPGA: U1.M2 (IO_2); also elsewhere on the board
DSACK0_FPGA: U1.B5 (IO_8); also elsewhere on the board
DSACK1_FPGA: U1.D6 (CRC_ERROR/IO_8); also elsewhere on the board
DS_FPGA: U1.F4 (IO_1B); also elsewhere on the board
DTACK_CBTD_FPGA: U1.L4 (IO_3); also elsewhere on the board
DTACK_FPGA: U1.J1 (IO_2); also elsewhere on the board
EA2_FPGA: U1.N6 (IO_3); also elsewhere on the board
EA3_FPGA: U1.N7 (IO_3); also elsewhere on the board
EBCLR_FPGA: U1.B4 (IO_8); also elsewhere on the board
EBG0_FPGA: U1.A8 (IO_8); also elsewhere on the board
EBG1_FPGA: U1.A7 (IO_8); also elsewhere on the board
EBG2_FPGA: U1.A3 (IO_8); also elsewhere on the board
EBG3_FPGA: U1.A2 (IO_8); also elsewhere on the board
EBG4_FPGA: U1.B2 (IO_8); also elsewhere on the board
EBGACK_FPGA: U1.F9 (DPCLK3/IO_6); also elsewhere on the board
EBR0_FPGA: U1.B10 (IO_8); also elsewhere on the board
EBR1_FPGA: U1.B11 (IO_6); also elsewhere on the board
EBR2_FPGA: U1.A12 (IO_6); also elsewhere on the board
EBR3_FPGA: U1.B12 (IO_6); also elsewhere on the board
EBR4_FPGA: U1.A11 (IO_8); also elsewhere on the board
EDS0_FPGA: U1.N8 (IO_3); also elsewhere on the board
EDS1_FPGA: U1.N5 (IO_3); also elsewhere on the board
EDS2_FPGA: U1.K2 (IO_2); also elsewhere on the board
EDS3_FPGA: U1.M3 (IO_2/PLL_L_CLKOUTn); also elsewhere on the board
FCS_FPGA: U1.M10 (IO_3); also elsewhere on the board
GND: C1.1, C2.1, C3.1, C4.1, C5.1, C6.1, C7.1, C8.1, C9.1, C10.1, C11.1, C12.1, C13.1, C14.1, C15.1, C16.1, C17.1, C18.1, C19.1, C20.1, C24.1, C25.1, C26.1, C27.1, C28.1, JTAG1.2, JTAG1.10, RN2.5 (R4.2), U1.A1 (GND), U1.A13 (GND), U1.B8 (GND), U1.C3 (GND), U1.D2 (GND), U1.D5 (GND), U1.D7 (CONFIG_SEL/IO_8), U1.E1 (IO_1A), U1.E2 (GND), U1.E6 (IO_8), U1.E8 (IO_8), U1.E9 (IO_6), U1.E10 (IO_6), U1.E11 (GND), U1.E12 (IO_6), U1.E13 (CLK3n/IO_6), U1.F3 (GND), U1.F8 (IO_6), U1.G7 (GND), U1.G10 (CLK2n/IO_6), U1.H12 (GND), U1.J4 (GND), U1.J5 (IO_3), U1.J6 (IO_3), U1.K5 (IO_3), U1.L3 (IO_2/PLL_L_CLKOUTp), U1.L5 (IO_3), U1.L9 (GND), U1.M6 (GND), U1.N1 (GND), U1.N2 (IO_2/DPCLK0), U1.N3 (IO_2/DPCLK1), U1.N13 (GND), U2.1 (GND); also elsewhere on the board
IOZ2_FPGA: U1.C11 (IO_6); also elsewhere on the board
LOCK_EA1_FPGA: U1.N4 (IO_3); also elsewhere on the board
MEMZ2_FPGA: U1.F10 (DPCLK2/IO_6); also elsewhere on the board
MS0_FPGA: U1.A10 (IO_8); also elsewhere on the board
MS1_FPGA: U1.B9 (DEV_CLRn/IO_8); also elsewhere on the board
MS2_FPGA: U1.G13 (IO_5); also elsewhere on the board
MTACK_FPGA: U1.M11 (IO_3); also elsewhere on the board
MTCR_CBTD_FPGA: U1.G9 (CLK2p/IO_6); also elsewhere on the board
MTCR_FPGA: U1.K1 (IO_2); also elsewhere on the board
OE_U4: RN2.2 (R2.1), U1.L1 (IO_2/VREFB2N0); also elsewhere on the board
OWN_FPGA: U1.C9 (IO_8); also elsewhere on the board
READ_FPGA: U1.M1 (IO_2); also elsewhere on the board
RESET_FPGA: U1.M5 (IO_3); also elsewhere on the board
RMC_FPGA: U1.K10 (IO_5); also elsewhere on the board
RW_FPGA: U1.N11 (IO_3/VREFB3N0); also elsewhere on the board
SBG_FPGA: U1.K12 (IO_5); also elsewhere on the board
SBR_FPGA: U1.K11 (IO_5); also elsewhere on the board
SIZ0_FPGA: U1.N12 (IO_3); also elsewhere on the board
SIZ1_FPGA: U1.M12 (IO_3); also elsewhere on the board
SLAVE0_FPGA: U1.C1 (IO_1A); also elsewhere on the board
SLAVE1_FPGA: U1.D1 (IO_1A); also elsewhere on the board
SLAVE2_FPGA: U1.F1 (IO_1A); also elsewhere on the board
SLAVE3_FPGA: U1.E3 (IO_1A); also elsewhere on the board
SLAVE4_FPGA: U1.B6 (IO_8); also elsewhere on the board
STERM_FPGA: U1.F12 (IO_6); also elsewhere on the board
TCK: JTAG1.1, RN2.4 (R4.1), U1.G2 (IO_1B/TCK)
TDI: JTAG1.9, RN2.1 (R1.1), U1.F5 (IO_1B/TDI)
TDO: JTAG1.3, U1.F6 (IO_1B/TDO)
TMS: JTAG1.5, RN2.3 (R3.1), U1.G1 (IO_1B/TMS)
VCC: C1.2, U2.3 (VI); also elsewhere on the board
WAIT_FPGA: U1.H8 (IO_5); also elsewhere on the board
nCONFIG: RN1.4 (R4.1), U1.D8 (DEV_OE/IO_8), U1.E7 (nCONFIG/Input_only_8)
nSTATUS: RN1.2 (R2.1), U1.C4 (nSTATUS/IO_8)

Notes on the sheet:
0603
0805

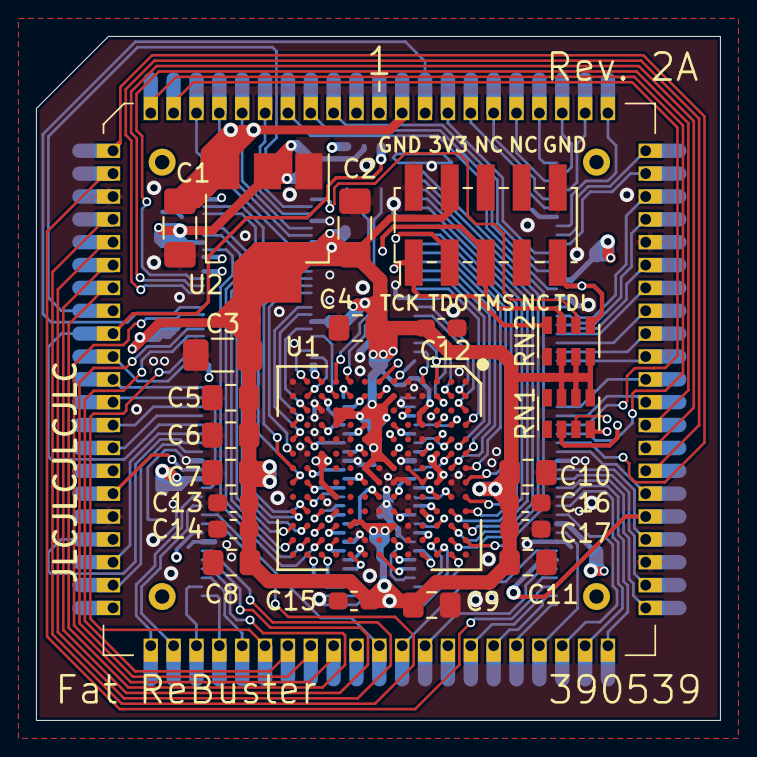
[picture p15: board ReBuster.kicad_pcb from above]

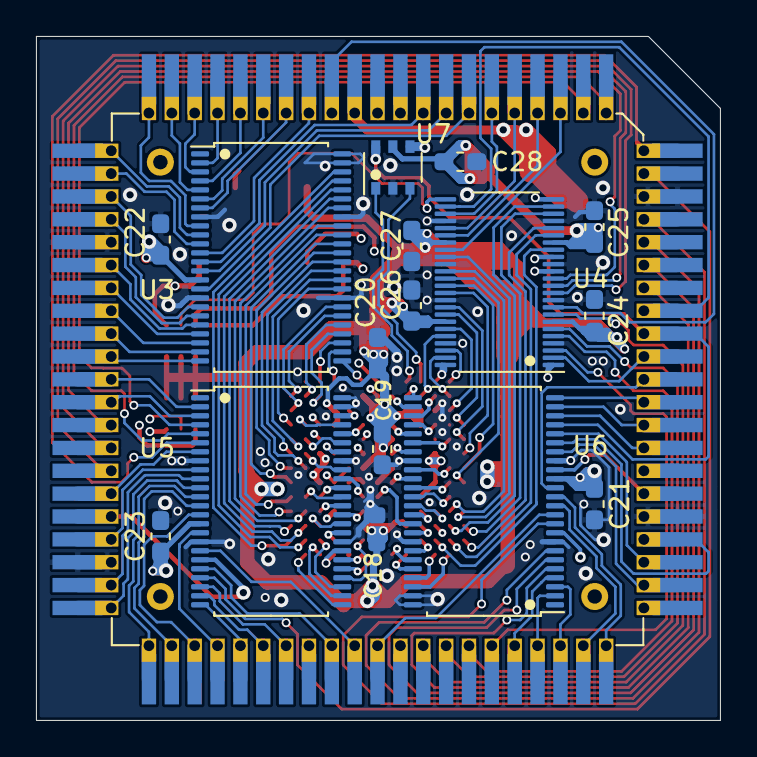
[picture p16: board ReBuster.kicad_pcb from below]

Board: 4 copper layers, 38.0 x 38.0 mm, 40 parts (17 on the bottom side), 168 nets.

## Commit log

2024-11-18 Add footprints
2024-11-18 Add base skel of ReBuster based on ReSDMAC design
    [ReBuster.kicad_pcb, ReBuster.sch, ReBuster_FPGA.sch]
2024-11-19 Adapted the design for Super Buster pinout, renamed all nets, assigned clk signals C7M,CPUCLK,CDAC,CLK90 to CLK0p,CLK1p,CLK2p,CLK3p, and re-routed where needed
    [ReBuster.kicad_pcb, ReBuster.sch, ReBuster_FPGA.sch]
2024-11-19 Corrected and verified direction assignment on all nets/pins and did some small routing fixes
    [ReBuster.kicad_pcb, ReBuster.sch, ReBuster_FPGA.sch]
2024-11-20 Silkscreen fixes on the CBTD footprints
    [ReBuster.kicad_pcb]
2024-11-20 Add rev1a schematic pdf
2024-11-20 Add BOM
2024-11-20 Corrected link to 3D-models of DIY-plug PCBs
    [ReBuster.kicad_pcb]
2024-12-20 Fix show U3,U4,U5,U6 references on silkscreen
    [ReBuster.kicad_pcb]
2025-01-19 small GND fix improvement for C22,C24 adding a second GND via
    [ReBuster.kicad_pcb]
2025-01-28 small routing improvement
    [ReBuster.kicad_pcb]
2025-03-21 Change RN1, RN2 value from 10k to 4.7k (CAY16A-4701F4LF) to follow Gowin JTAG recommended design.
    [ReBuster.kicad_pcb, ReBuster_FPGA.sch]
2025-03-22 Change U1 from 10M02SCU169C8G to pin compatible Gowin FPGA GW1N-UV9UG169C6/I5
    [ReBuster.kicad_pcb, ReBuster_FPGA.sch]
2025-03-22 Add pdf schematic rev. 1a
2026-02-22 update footprint
2026-02-22 Change back to a 10M02SCU169 FPGA
    [ReBuster.kicad_pcb, ReBuster_FPGA.sch]
2026-02-22 replace U4 (SN74CBTD16210) with a SN74LVC16T245DGVR
    [ReBuster.kicad_pcb, ReBuster.sch]
2026-02-22 Fix pad size on U4 footprint
    [ReBuster.kicad_pcb]
2026-02-23 Add 74LVC2T45DC for handling DTACKn and MTACKn
    [ReBuster.kicad_pcb, ReBuster.sch, ReBuster_FPGA.sch]
2026-02-23 Route AS,SIZ1,SIZ0,RW to U4 (SN74LVC16T245DGVR) and FPGA
    [ReBuster.kicad_pcb, ReBuster.sch, ReBuster_FPGA.sch]
2026-02-23 Route EDS1, CCS, FCS signals to U4 (SN74LVC16T245DGVR) and FPGA
    [ReBuster.kicad_pcb, ReBuster.sch, ReBuster_FPGA.sch]
2026-02-24 Relocate A0,A1,A2 to FPGA pin A4,A5,A6 and route traces
    [ReBuster.kicad_pcb, ReBuster.sch, ReBuster_FPGA.sch]
2026-02-24 Remove JP1 and assign its pull-up resistor to OE_U4
    [ReBuster.kicad_pcb, ReBuster.sch, ReBuster_FPGA.sch]
2026-02-24 Add pull-down resistor to DIR_U7 and assign N9-pin and route trace
    [ReBuster.kicad_pcb, ReBuster_FPGA.sch]
2026-02-24 Route DOE to U4 (SN74LVC16T245DGVR) change J1 -> M2 in FPGA
    [ReBuster.kicad_pcb, ReBuster.sch, ReBuster_FPGA.sch]
2026-02-24 Add 0.6 x 0.3 mm via
2026-02-24 Route READ to U4 (SN74LVC16T245DGVR) change H13 -> M1 in FPGA
    [ReBuster.kicad_pcb, ReBuster.sch, ReBuster_FPGA.sch]
2026-02-24 Route STERM change N10 -> F12 in FPGA
    [ReBuster.kicad_pcb, ReBuster.sch, ReBuster_FPGA.sch]
2026-02-24 Route EDS2 to U4 (SN74LVC16T245DGVR) change K13 -> K2 in FPGA
    [ReBuster.kicad_pcb, ReBuster.sch, ReBuster_FPGA.sch]
2026-02-24 Route EDS3 to U4 (SN74LVC16T245DGVR) change K12 -> M3 in FPGA
    [ReBuster.kicad_pcb, ReBuster.sch, ReBuster_FPGA.sch]
2026-02-24 Route EA1_LOCK to U4 (SN74LVC16T245DGVR) change K10 -> N4 in FPGA
    [ReBuster.kicad_pcb, ReBuster.sch, ReBuster_FPGA.sch]
2026-02-24 Route MTCR to U4 (SN74LVC16T245DGVR) change F12 -> N5 in FPGA
    [ReBuster.kicad_pcb, ReBuster.sch, ReBuster_FPGA.sch]
2026-02-25 Route EA2,EA3 to U4 (SN74LVC16T245DGVR) change D6 -> N6, B5 -> N7 in FPGA
    [ReBuster.kicad_pcb, ReBuster.sch, ReBuster_FPGA.sch]
2026-02-25 Route EDS0 to U4 (SN74LVC16T245DGVR) change F4 -> N8 in FPGA
    [ReBuster.kicad_pcb, ReBuster.sch, ReBuster_FPGA.sch]
2026-02-25 Route RMC, SBR, SBG, CIIN to U6 (SN74CBTD16210) and assign pins K10, K11, K12, H13 in FPGA respectively
    [ReBuster.kicad_pcb, ReBuster.sch, ReBuster_FPGA.sch]
2026-02-25 small routing fixes upgrading 0.45/0.2 mm vias to 0.5/0.3 mm where possible
    [ReBuster.kicad_pcb, ReBuster.sch, ReBuster_FPGA.sch]
2026-02-25 Change resistor networks (RN1,RN2) to 10k Ohm
    [ReBuster.kicad_pcb, ReBuster_FPGA.sch]
2026-02-25 Add 0603 modified cap footprint
2026-02-25 Add VCC cap for U7 (74LVC2T45DC)
    [ReBuster.kicad_pcb, ReBuster.sch]
2026-02-25 Add two caps for 3.3v input pins on U4 (SN74LVC16T245DGVR)
    [ReBuster.kicad_pcb, ReBuster_FPGA.sch]
2026-02-25 Route 3.3v to U4 via caps and optimize via placements
    [ReBuster.kicad_pcb, ReBuster_FPGA.sch]
2026-02-26 Silkscreen fixes
    [ReBuster.kicad_pcb, ReBuster.sch]
2026-02-26 Silkscreen fix, indicate pin 1 with a dot on U4 and U7
    [ReBuster.kicad_pcb]
2026-03-01 remove CDAC clock (not used) and put /MTCR signal there
    [ReBuster.kicad_pcb, ReBuster.sch, ReBuster_FPGA.sch]
2026-03-01 remove HLT-signal (not used) and put /DTACK signal there
    [ReBuster.kicad_pcb, ReBuster.sch, ReBuster_FPGA.sch]
2026-03-02 Replace 74LVC2T45DC with 74LVC2G07GV and prepare rerouting, reroute /DTACK
    [ReBuster.kicad_pcb, ReBuster.sch]
2026-03-02 Relocate EDS1 signal to replace MTCR's position (pin 9 and 40) in SN74LVC16T245
    [ReBuster.kicad_pcb, ReBuster.sch, ReBuster_FPGA.sch]
2026-03-02 Add footprint
2026-03-02 Replace SN74LVC16T245DGVR with SN74LVC16245ADGVR and fix caps C24,C25 to instead be connected to 3V3
    [ReBuster.kicad_pcb, ReBuster.sch, ReBuster_FPGA.sch]
2026-03-02 Assign MTACK to pin 23,26 in SN74LVC16245 and M11 in FPGA and route trace
    [ReBuster.kicad_pcb, ReBuster.sch, ReBuster_FPGA.sch]
2026-03-02 Assign RW to pin 22,27 in SN74LVC16245 and route trace
    [ReBuster.kicad_pcb, ReBuster.sch]
2026-03-02 Assign SIZ0 to pin 20,29 in SN74LVC16245 and route trace
    [ReBuster.kicad_pcb, ReBuster.sch]
2026-03-02 Assign SIZ1 to pin 19,30 in SN74LVC16245 and M12 in FPGA and route trace
    [ReBuster.kicad_pcb, ReBuster.sch, ReBuster_FPGA.sch]
2026-03-02 Assign AS to pin 17,32 in SN74LVC16245 and L12 in FPGA and route trace
    [ReBuster.kicad_pcb, ReBuster.sch, ReBuster_FPGA.sch]
2026-03-02 Some small power routing improvements and via positioning
    [ReBuster.kicad_pcb, ReBuster_FPGA.sch]
2026-03-02 Change C18 from handsolder footprint to normal
    [ReBuster.kicad_pcb, ReBuster_FPGA.sch]
2026-03-03 Small silkscreen fixes, remove silkscreen over vias and better positioning of some designators
    [ReBuster.kicad_pcb]
2026-03-04 small grounding improvement set C9 GND pad to solid pad connection
    [ReBuster.kicad_pcb]
2026-03-04 Add schematic pdf
2026-03-05 Update README.md
    Add Rev 2A BOM and pin assignment figure.

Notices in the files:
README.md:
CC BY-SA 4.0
